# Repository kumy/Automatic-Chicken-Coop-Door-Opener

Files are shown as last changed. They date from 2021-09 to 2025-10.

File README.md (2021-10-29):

# Automatic Chicken Coop Door Opener

Here is my personal implementation of an Automatic Chicken Coop Door Opener. It has direct control button, a simple web interface with camera support and can be controlled via `MQTT` protocol. It is integrated in my home automation system.

This project requires materials:
- 3D printed parts
- An `Arduino` (duemilanove in my case, but any board should be okay)
- A `Raspberry` Pi (3 A+ in my case)
- `Raspberry Pi Camera` + `SV-6B` Infrared Ring (optional)
- A Stepper motor (project could be adapted to support DC motors)
- A Stepper driver (`DRV8825` in my case)
- A [Push Button Switch Box](https://www.aliexpress.com/item/4000121428780.html)
- A [box](https://www.aliexpress.com/item/33003227855.html) to protect electronics
- A `DS18b20` Temperature sensor
- Two [magnetic door sensor](https://www.amazon.fr/gp/product/B082PM18V6/) (I've choose mine brown)
- Some 4 wires cables, dupont cables and [Solder Seal Wire Connectors](https://www.aliexpress.com/item/1005002662810874.html)
- A [Waterproof Electrical Distribution Box](https://www.aliexpress.com/item/4001061820250.html)
- `5V` and `12V` [Industrial DIN Rail Switching Power Supply](https://www.aliexpress.com/item/4001289041252.html)
- 13cm diameter 8 steel rod
- Two `608` bearings
- Some washers and screws

# Raspberry Pi software installation

- First install your preferred Linux distribution (I've simply used Raspberry Pi
 OS).
- (optional) Install `motion`: `sudo apt install motion` (my config file in the `other` directory) and make it start at boot (edit `/etc/default/motion`)
- Install `redis server`: `sudo apt install redis-server` and enable start on boot `sudo systemctl enable redis-server`
- Clone this project GIT repository
- Install python required libraries: `sudo pip3 install -r requirements.txt`
- Install `gunicorn3` and `authbind`: `sudo apt install gunicorn3 authbind`
- Configure `authbind`: `sudo touch /etc/authbind/byport/80; sudo chmod 500 /etc/authbind/byport/80; sudo chown pi /etc/authbind/byport/80`
- Copy file `other/chicken-coop.service` to `/etc/systemd/system/chicken-coop.service`, then reload systemd (`sudo systemctl daemon-reload`) and enable the service `sudo systemctl enable chicken-coop.service`

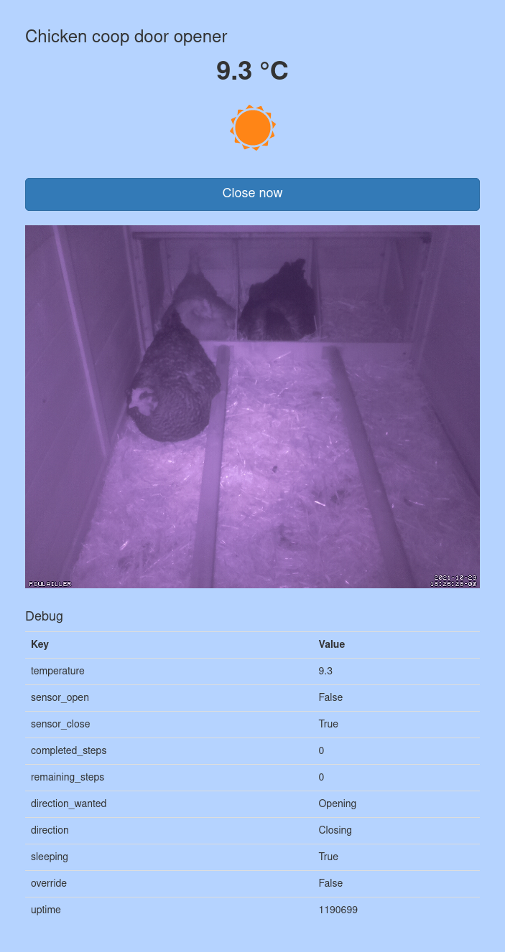
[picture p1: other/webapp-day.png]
WebAPP Day

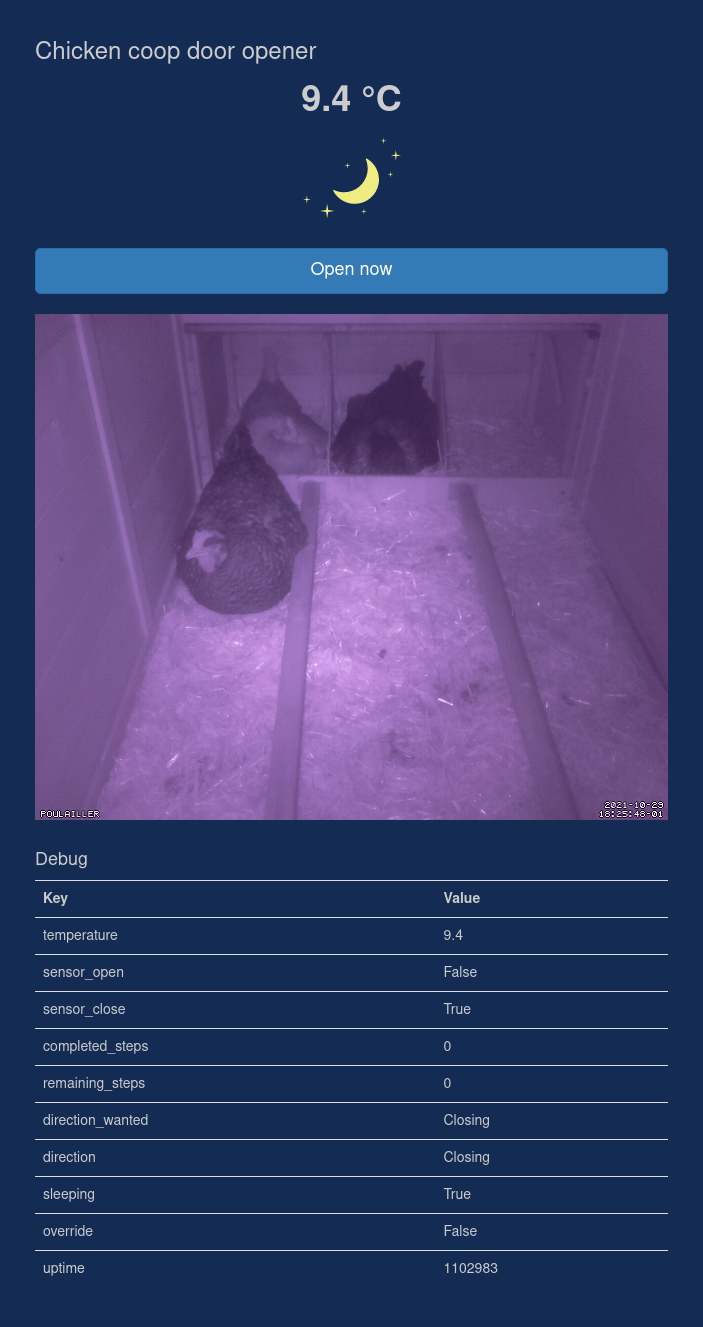
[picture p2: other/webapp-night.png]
WebAPP Day


# Electronic assembly

Please refer to the schema below to connect elements. Also **connect the Arduino to the Raspberry Pi via USB**, this is needed as they are communicating internally.

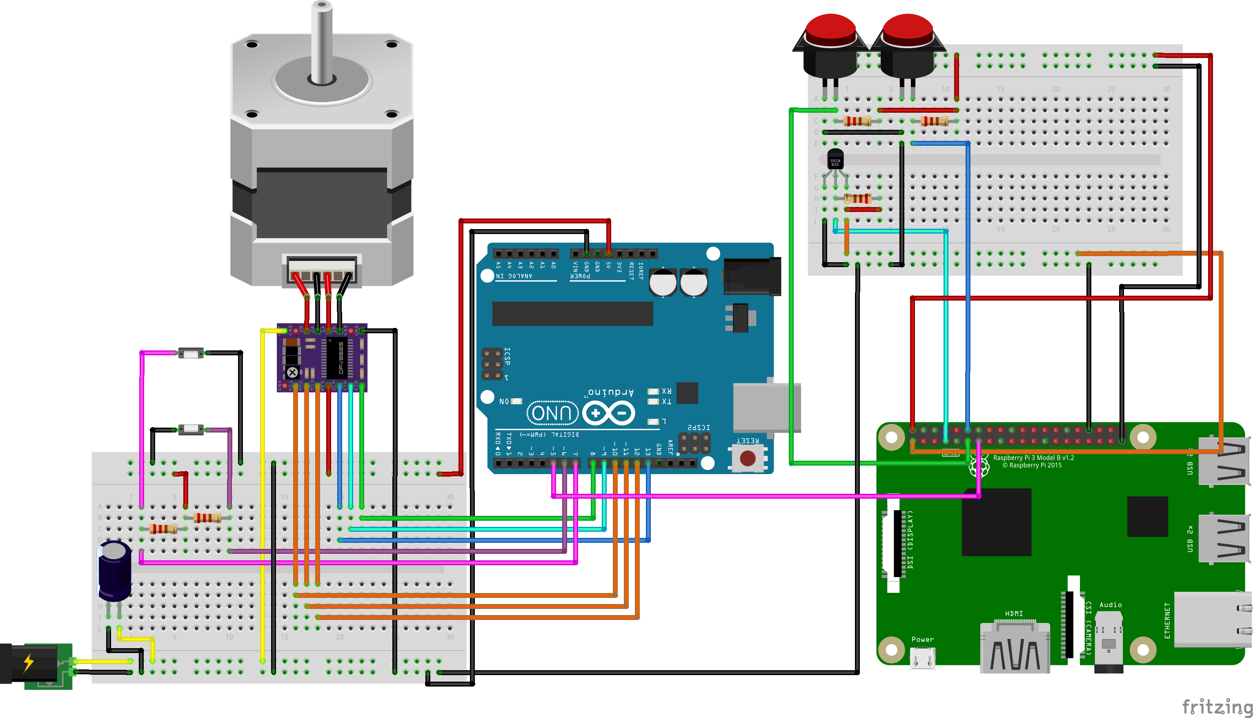
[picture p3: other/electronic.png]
Electronic assembly


## Arduino firmware upload

You'll find the arduino firmware in the `other/chicken_coop_arduino_v2` folder. You'll need to install libraries `ArduinoJson` and `StepperDriver`.

# Print 3D parts

Print files from folder `other/3D-parts`:
- `box.stl`
- `lead.stl`
- `drive-gear.stl`
- `stepper-gear.stl`
- `winder.stl`
- `IR-holder.stl`
- `IR-holder-base.stl`
- `case-without-clip.stl` (use some glue to paste it on `IR-holder.stl`)

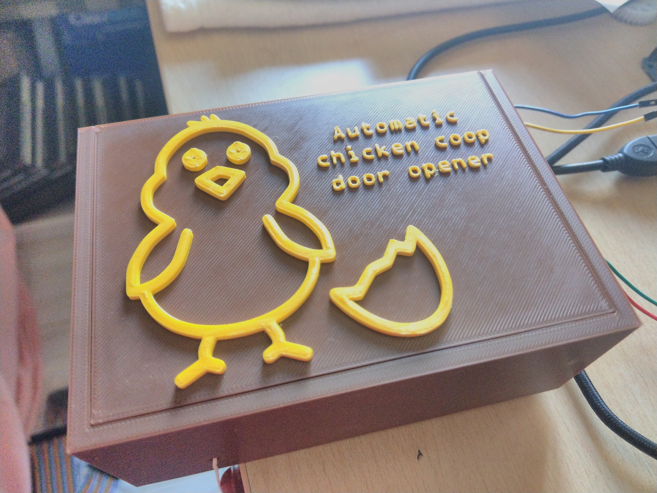
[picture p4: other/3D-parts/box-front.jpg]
Box front Front

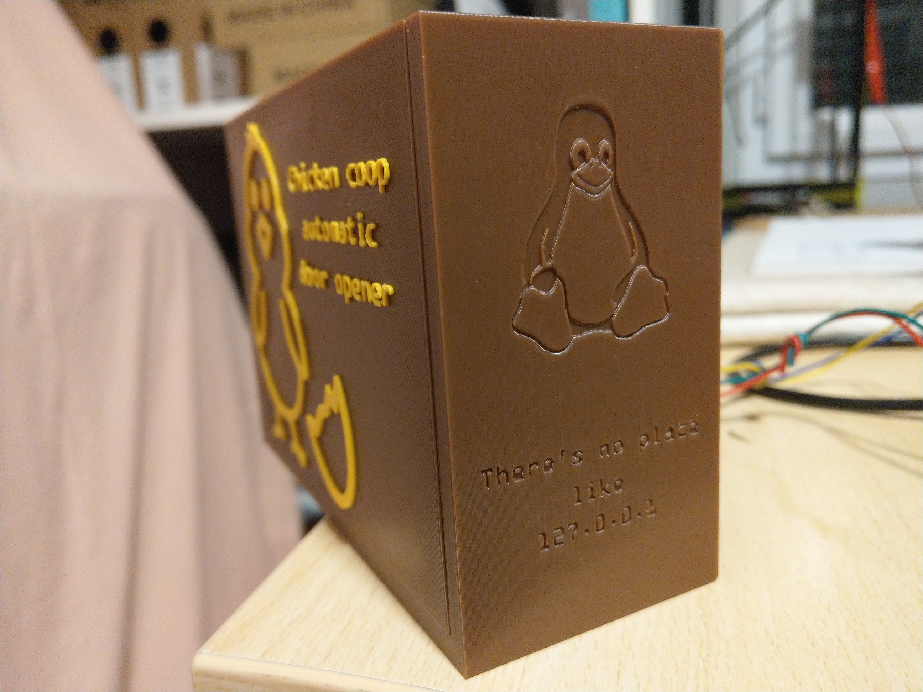
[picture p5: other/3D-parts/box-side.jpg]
Box side Side

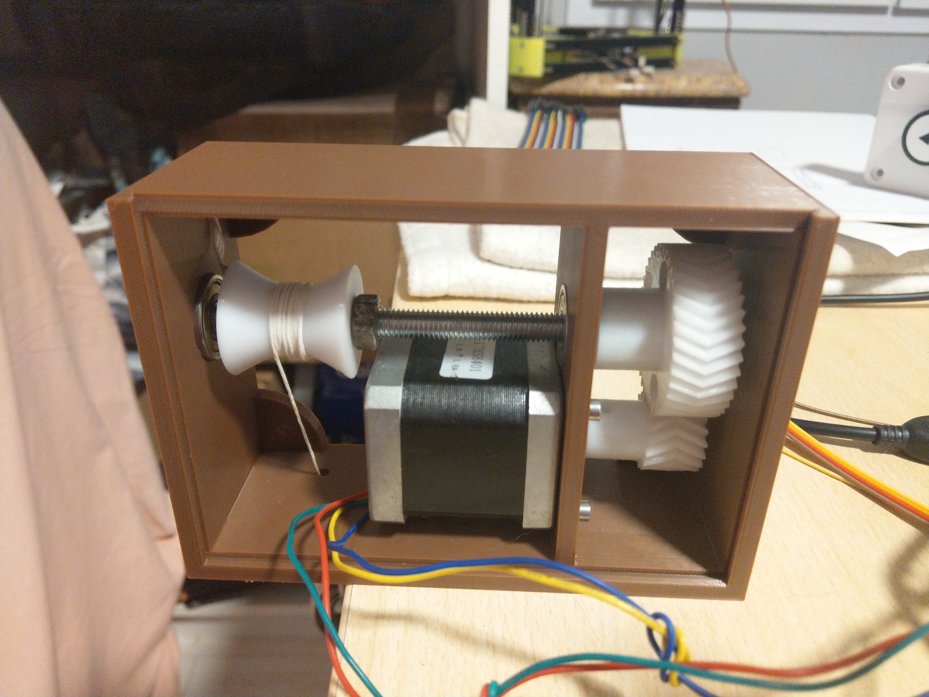
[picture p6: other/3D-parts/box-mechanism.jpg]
Box mechanism Mechanism


# Node-RED

I use [Node-RED](https://nodered.org/) to automate opening/closing the door according to the sun position.

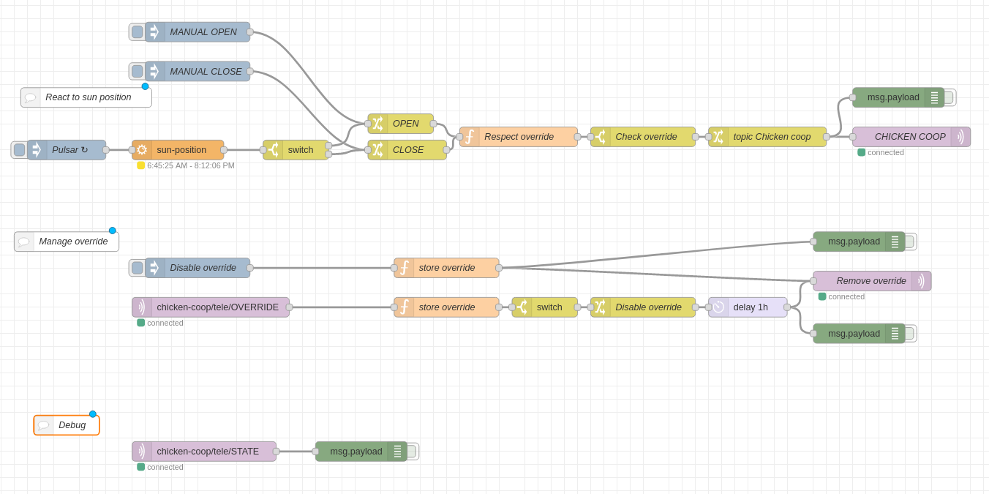
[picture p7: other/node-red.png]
Box front


```
[{"id":"c7d25223.e79a98","type":"tab","label":"Chicken coop","disabled":false,"info":""},{"id":"a1a07d72.5bd8","type":"inject","z":"c7d25223.e79a98","name":"MANUAL OPEN","props":[{"p":"payload"}],"repeat":"","crontab":"","once":false,"onceDelay":0.1,"topic":"","payload":"True","payloadType":"str","x":640,"y":100,"wires":[["fd09d4f.2c761a8","c0e33773.e7af7"]]},{"id":"5502c773.69c1b8","type":"inject","z":"c7d25223.e79a98","name":"MANUAL CLOSE","props":[{"p":"payload"}],"repeat":"","crontab":"","once":false,"onceDelay":0.1,"topic":"","payload":"True","payloadType":"str","x":640,"y":140,"wires":[["fd09d4f.2c761a8","2bb7edef.acf7e2"]]},{"id":"666bfd51.be461c","type":"change","z":"c7d25223.e79a98","name":"OPEN","rules":[{"t":"set","p":"payload","pt":"msg","to":"OPEN","tot":"str"}],"action":"","property":"","from":"","to":"","reg":false,"x":810,"y":280,"wires":[["63d5a226.1bf514"]]},{"id":"a247530a.950348","type":"change","z":"c7d25223.e79a98","name":"CLOSE","rules":[{"t":"set","p":"payload","pt":"msg","to":"CLOSE","tot":"str"}],"action":"","property":"","from":"","to":"","reg":false,"x":820,"y":340,"wires":[["63d5a226.1bf514"]]},{"id":"c711ead2.5034b8","type":"debug","z":"c7d25223.e79a98","name":"","active":false,"tosidebar":true,"console":false,"tostatus":false,"complete":"false","x":1510,"y":120,"wires":[]},{"id":"5edadbf0.16693c","type":"mqtt out","z":"c7d25223.e79a98","name":"CHICKEN COOP","topic":"chicken-coop/cmnd/ACTION","qos":"","retain":"","broker":"499038ea.d2406","x":1530,"y":260,"wires":[]},{"id":"6a6f2f23.bda448","type":"mqtt in","z":"c7d25223.e79a98","name":"","topic":"chicken-coop/tele/STATE","qos":"2","datatype":"auto","broker":"499038ea.d2406","x":430,"y":760,"wires":[["186cc186.50ee46"]]},{"id":"b574a3b.f240fe","type":"debug","z":"c7d25223.e79a98","name":"","active":false,"tosidebar":true,"console":false,"tostatus":false,"complete":"false","x":1010,"y":760,"wires":[]},{"id":"470b9cb6.7c8c3c","type":"sun-position","z":"c7d25223.e79a98","name":"","positionConfig":"9a8aa319.57d4a8","rules":[],"onlyOnChange":"true","topic":"","outputs":1,"start":"civilDawn","startType":"pdsTime","startOffset":"","startOffsetType":"none","startOffsetMultiplier":60000,"end":"civilDusk","endType":"pdsTime","endOffset":"-40","endOffsetType":"num","endOffsetMultiplier":"60000","x":390,"y":320,"wires":[["745ca347.8275c4","97193675.7260f8"]]},{"id":"4abdc73f.09fec8","type":"inject","z":"c7d25223.e79a98","name":"Pulsar","props":[{"p":"payload"},{"p":"topic","vt":"str"}],"repeat":"60","crontab":"","once":true,"onceDelay":0.1,"topic":"","payload":"","payloadType":"date","x":220,"y":320,"wires":[["470b9cb6.7c8c3c"]]},{"id":"97193675.7260f8","type":"switch","z":"c7d25223.e79a98","name":"sunInSky?","property":"payload.sunInSky","propertyType":"msg","rules":[{"t":"true"},{"t":"false"}],"checkall":"true","repair":false,"outputs":2,"x":630,"y":320,"wires":[["666bfd51.be461c"],["a247530a.950348"]]},{"id":"4dd9039d.c1e154","type":"mqtt in","z":"c7d25223.e79a98","name":"","topic":"chicken-coop/cmnd/OVERRIDE","qos":"2","datatype":"auto","broker":"499038ea.d2406","x":450,"y":600,"wires":[["5fbb85e.d93fe7c","35cb803c.ddd72"]]},{"id":"5fbb85e.d93fe7c","type":"function","z":"c7d25223.e79a98","name":"store override","func":"\n/* store state back into state machine */\nglobal.set('state.chicken-coop.override', msg.payload == \"True\");\n\nreturn msg;","outputs":1,"noerr":0,"initialize":"","finalize":"","x":760,"y":560,"wires":[["d9b4a67a.acd348"]]},{"id":"d9b4a67a.acd348","type":"switch","z":"c7d25223.e79a98","name":"IsOverride?","property":"payload","propertyType":"msg","rules":[{"t":"eq","v":"True","vt":"str"}],"checkall":"true","repair":false,"outputs":1,"x":930,"y":560,"wires":[["3ac436d.57ae84a"]]},{"id":"3ac436d.57ae84a","type":"change","z":"c7d25223.e79a98","name":"Disable override","rules":[{"t":"set","p":"payload","pt":"msg","to":"False","tot":"str"}],"action":"","property":"","from":"","to":"","reg":false,"x":1100,"y":560,"wires":[["5a4e03ee.41194c"]]},{"id":"104d8435.acb36c","type":"debug","z":"c7d25223.e79a98","name":"","active":false,"tosidebar":true,"console":false,"tostatus":false,"complete":"false","x":1510,"y":600,"wires":[]},{"id":"f03327b8.42df","type":"mqtt out","z":"c7d25223.e79a98","name":"","topic":"chicken-coop/cmnd/OVERRIDE","qos":"","retain":"","broker":"499038ea.d2406","x":1570,"y":500,"wires":[]},{"id":"546f0d20.38d7e4","type":"inject","z":"c7d25223.e79a98","name":"Disable override","props":[{"p":"payload"}],"repeat":"","crontab":"","once":false,"onceDelay":0.1,"topic":"","payload":"False","payloadType":"str","x":440,"y":480,"wires":[["f03327b8.42df"]]},{"id":"60c97cb0.cab624","type":"comment","z":"c7d25223.e79a98","name":"React to sun position","info":"","x":250,"y":240,"wires":[]},{"id":"58597c67.21380c","type":"comment","z":"c7d25223.e79a98","name":"Manage override","info":"","x":220,"y":460,"wires":[]},{"id":"14b453f.d74912c","type":"comment","z":"c7d25223.e79a98","name":"Debug","info":"","x":170,"y":1100,"wires":[]},{"id":"35cb803c.ddd72","type":"debug","z":"c7d25223.e79a98","name":"","active":false,"tosidebar":true,"console":false,"tostatus":false,"complete":"false","statusVal":"","statusType":"auto","x":750,"y":620,"wires":[]},{"id":"60601a56.7f041c","type":"debug","z":"c7d25223.e79a98","name":"","active":true,"tosidebar":true,"console":false,"tostatus":false,"complete":"false","statusVal":"","statusType":"auto","x":770,"y":1140,"wires":[]},{"id":"3c4749ab.162266","type":"inject","z":"c7d25223.e79a98","name":"Read override","props":[],"repeat":"","crontab":"","once":false,"onceDelay":0.1,"topic":"","x":390,"y":1140,"wires":[["37e30002.79cbb"]]},{"id":"37e30002.79cbb","type":"function","z":"c7d25223.e79a98","name":"isOverridden?","func":"\n/* store state back into state machine */\nmsg.payload = global.get('state.chicken-coop.override');\n\nreturn msg;","outputs":1,"noerr":0,"initialize":"","finalize":"","x":600,"y":1140,"wires":[["60601a56.7f041c"]]},{"id":"54d75f5.38342a","type":"inject","z":"c7d25223.e79a98","name":"Enable override","props":[{"p":"payload"}],"repeat":"","crontab":"","once":false,"onceDelay":0.1,"topic":"","payload":"True","payloadType":"str","x":440,"y":520,"wires":[["f03327b8.42df"]]},{"id":"5a4e03ee.41194c","type":"stoptimer","z":"c7d25223.e79a98","duration":"6","units":"Hour","payloadtype":"num","payloadval":"0","name":"","x":1290,"y":560,"wires":[["f03327b8.42df","104d8435.acb36c"],[]]},{"id":"a9ff0fb9.bc101","type":"inject","z":"c7d25223.e79a98","name":"Stop Timer","props":[{"p":"payload"}],"repeat":"","crontab":"","once":false,"onceDelay":0.1,"topic":"","payload":"STOP","payloadType":"str","x":1100,"y":660,"wires":[["5a4e03ee.41194c","be497be1.a9ea5"]]},{"id":"fd09d4f.2c761a8","type":"mqtt out","z":"c7d25223.e79a98","name":"","topic":"chicken-coop/cmnd/OVERRIDE","qos":"","retain":"","broker":"499038ea.d2406","x":1050,"y":40,"wires":[]},{"id":"32152b3.f4826d4","type":"debug","z":"c7d25223.e79a98","name":"","active":true,"tosidebar":true,"console":false,"tostatus":false,"complete":"false","statusVal":"","statusType":"auto","x":770,"y":1180,"wires":[]},{"id":"eeb76486.eddd1","type":"inject","z":"c7d25223.e79a98","name":"Read Position","props":[],"repeat":"","crontab":"","once":false,"onceDelay":0.1,"topic":"","x":390,"y":1180,"wires":[["c5474891.8ae5f8"]]},{"id":"c5474891.8ae5f8","type":"function","z":"c7d25223.e79a98","name":"isClosed?","func":"\n/* store state back into state machine */\nmsg.payload = global.get('state.chicken-coop.closed');\n\nreturn msg;","outputs":1,"noerr":0,"initialize":"","finalize":"","x":580,"y":1180,"wires":[["32152b3.f4826d4"]]},{"id":"186cc186.50ee46","type":"json","z":"c7d25223.e79a98","name":"","property":"payload","action":"","pretty":false,"x":630,"y":760,"wires":[["4e5b3f48.015bd"]]},{"id":"4e5b3f48.015bd","type":"function","z":"c7d25223.e79a98","name":"storePosition","func":"\n/* store state back into state machine */\nglobal.set('state.chicken-coop.closed', msg.payload.sensor_close == true);\n\nif (msg.payload.direction_wanted == 'Closing') {\n    global.set('state.chicken-coop.direction', 'CLOSE');\n} else {\n    global.set('state.chicken-coop.direction', 'OPEN');\n}\n\nreturn msg;","outputs":1,"noerr":0,"initialize":"","finalize":"","x":790,"y":760,"wires":[["b574a3b.f240fe","7bf97c0b.a1ba54"]]},{"id":"745ca347.8275c4","type":"debug","z":"c7d25223.e79a98","name":"","active":false,"tosidebar":true,"console":false,"tostatus":false,"complete":"false","statusVal":"","statusType":"auto","x":560,"y":380,"wires":[]},{"id":"be497be1.a9ea5","type":"change","z":"c7d25223.e79a98","name":"Disable override","rules":[{"t":"set","p":"payload","pt":"msg","to":"False","tot":"str"}],"action":"","property":"","from":"","to":"","reg":false,"x":1300,"y":660,"wires":[["104d8435.acb36c","f03327b8.42df"]]},{"id":"8fd65612.1fe63","type":"mqtt out","z":"c7d25223.e79a98","name":"","topic":"chicken-coop/tele/OVERRIDE","qos":"","retain":"","broker":"499038ea.d2406","x":1570,"y":940,"wires":[]},{"id":"cb084a44.8375f","type":"function","z":"c7d25223.e79a98","name":"readOverride","func":"\n/* store state back into state machine */\nmsg.payload = global.get('state.chicken-coop.override');\n\nreturn msg;","outputs":1,"noerr":0,"initialize":"","finalize":"","x":1310,"y":940,"wires":[["8fd65612.1fe63","5b164d4c.87ba54"]]},{"id":"34d8774f.bde0e","type":"inject","z":"c7d25223.e79a98","name":"Pulsar","props":[{"p":"payload"},{"p":"topic","vt":"str"}],"repeat":"300","crontab":"","once":true,"onceDelay":0.1,"topic":"","payload":"","payloadType":"date","x":220,"y":940,"wires":[["cb084a44.8375f"]]},{"id":"5b164d4c.87ba54","type":"debug","z":"c7d25223.e79a98","name":"","active":false,"tosidebar":true,"console":false,"tostatus":false,"complete":"false","statusVal":"","statusType":"auto","x":1520,"y":1000,"wires":[]},{"id":"7bf97c0b.a1ba54","type":"switch","z":"c7d25223.e79a98","name":"Is DirectionSameAsAuto?","property":"state.chicken-coop.direction","propertyType":"global","rules":[{"t":"eq","v":"state.chicken-coop.direction_auto","vt":"global"}],"checkall":"true","repair":false,"outputs":1,"x":1050,"y":820,"wires":[["be497be1.a9ea5"]]},{"id":"946ce4dc.017a88","type":"switch","z":"c7d25223.e79a98","name":"IsNotOverridden?","property":"state.chicken-coop.override","propertyType":"global","rules":[{"t":"false"}],"checkall":"true","repair":false,"outputs":1,"x":1230,"y":340,"wires":[["c711ead2.5034b8","5edadbf0.16693c"]]},{"id":"c0e33773.e7af7","type":"change","z":"c7d25223.e79a98","name":"OPEN","rules":[{"t":"set","p":"payload","pt":"msg","to":"OPEN","tot":"str"}],"action":"","property":"","from":"","to":"","reg":false,"x":970,"y":100,"wires":[["5edadbf0.16693c","c711ead2.5034b8"]]},{"id":"2bb7edef.acf7e2","type":"change","z":"c7d25223.e79a98","name":"CLOSE","rules":[{"t":"set","p":"payload","pt":"msg","to":"CLOSE","tot":"str"}],"action":"","property":"","from":"","to":"","reg":false,"x":980,"y":140,"wires":[["5edadbf0.16693c","c711ead2.5034b8"]]},{"id":"63d5a226.1bf514","type":"function","z":"c7d25223.e79a98","name":"storeDirectionAuto","func":"\n/* store state back into state machine */\nglobal.set('state.chicken-coop.direction_auto', msg.payload);\n\nreturn msg;","outputs":1,"noerr":0,"initialize":"","finalize":"","x":1010,"y":340,"wires":[["946ce4dc.017a88"]]},{"id":"68e3560f.696ce8","type":"debug","z":"c7d25223.e79a98","name":"","active":true,"tosidebar":true,"console":false,"tostatus":false,"complete":"false","statusVal":"","statusType":"auto","x":770,"y":1220,"wires":[]},{"id":"7b02d608.3a1578","type":"inject","z":"c7d25223.e79a98","name":"Read Direction Auto","props":[],"repeat":"","crontab":"","once":false,"onceDelay":0.1,"topic":"","x":410,"y":1220,"wires":[["1ab3a071.b7dd38"]]},{"id":"1ab3a071.b7dd38","type":"function","z":"c7d25223.e79a98","name":"direction_auto","func":"\n/* store state back into state machine */\nmsg.payload = global.get('state.chicken-coop.direction_auto');\n\nreturn msg;","outputs":1,"noerr":0,"initialize":"","finalize":"","x":600,"y":1220,"wires":[["68e3560f.696ce8"]]},{"id":"499038ea.d2406","type":"mqtt-broker","name":"MQTT - NAS","broker":"nas.house.kumy.net","port":"1883","clientid":"","usetls":false,"compatmode":false,"keepalive":"60","cleansession":true,"birthTopic":"","birthQos":"0","birthPayload":"","closeTopic":"","closeQos":"0","closePayload":"","willTopic":"","willQos":"0","willPayload":""},{"id":"9a8aa319.57d4a8","type":"position-config","name":"House","isValide":"true","longitude":"0","latitude":"0","angleType":"deg","timeZoneOffset":99,"timeZoneDST":0,"stateTimeFormat":"3","stateDateFormat":"12"}]
```

# License

This project is released under [GNU GPLv3](LICENSE) license.

# Credits

- The chicken egg is from [Icon Fonts](https://www.onlinewebfonts.com/icon/552882) and is licensed by CC BY 3.0
- The day night original svg is from [Free SVG](https://freesvg.org/day-and-night) and is licensed as Public Domain
- The electronic schematic image was generated using a self build [Fritzing](https://fritzing.org/) install.
- The Pi Camera mount with infrared ring is a derivative of [Thing ico
Simple PiCam Case/Mount](https://www.thingiverse.com/thing:2613031), [Infrared Ring Mount SV-6B](https://www.thingiverse.com/thing:643221) and [GoPro customizable mounts, and a library to expand](https://www.thingiverse.com/thing:62800)

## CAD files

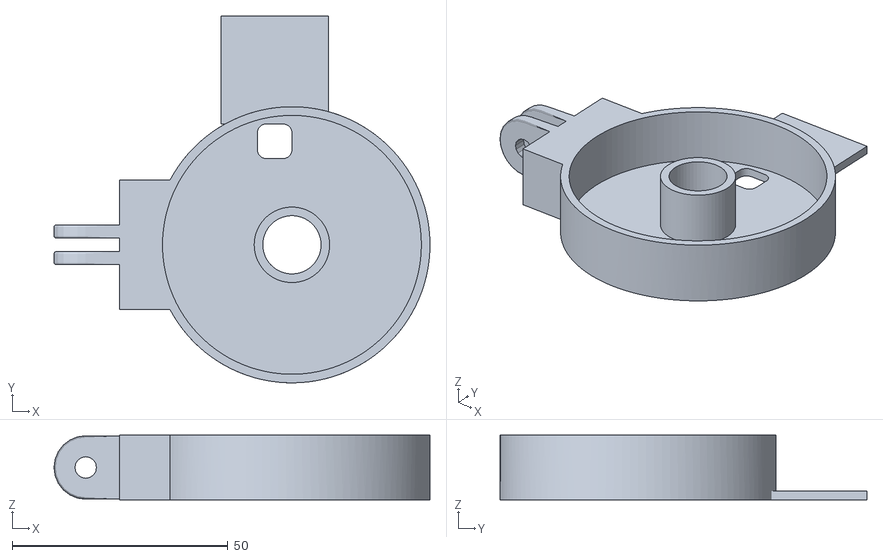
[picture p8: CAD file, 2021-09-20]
other/3D-parts/IR-holder.stl
87.2 x 85.0 x 15.0

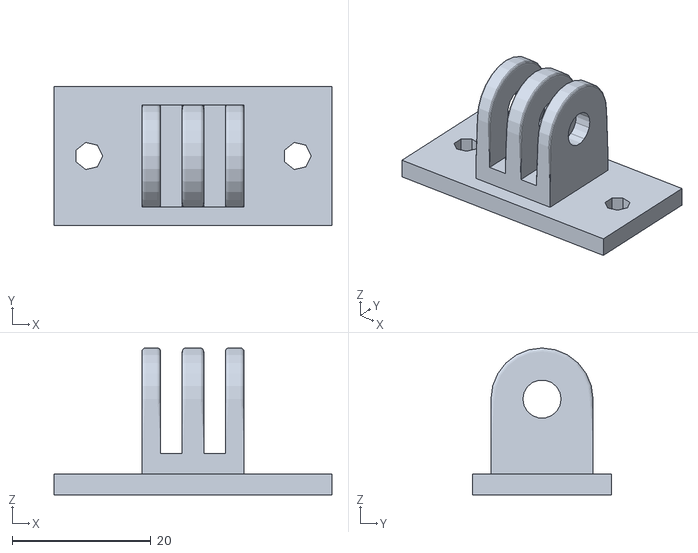
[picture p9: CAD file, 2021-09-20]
other/3D-parts/IR-holder-base.stl
40.0 x 20.0 x 21.1

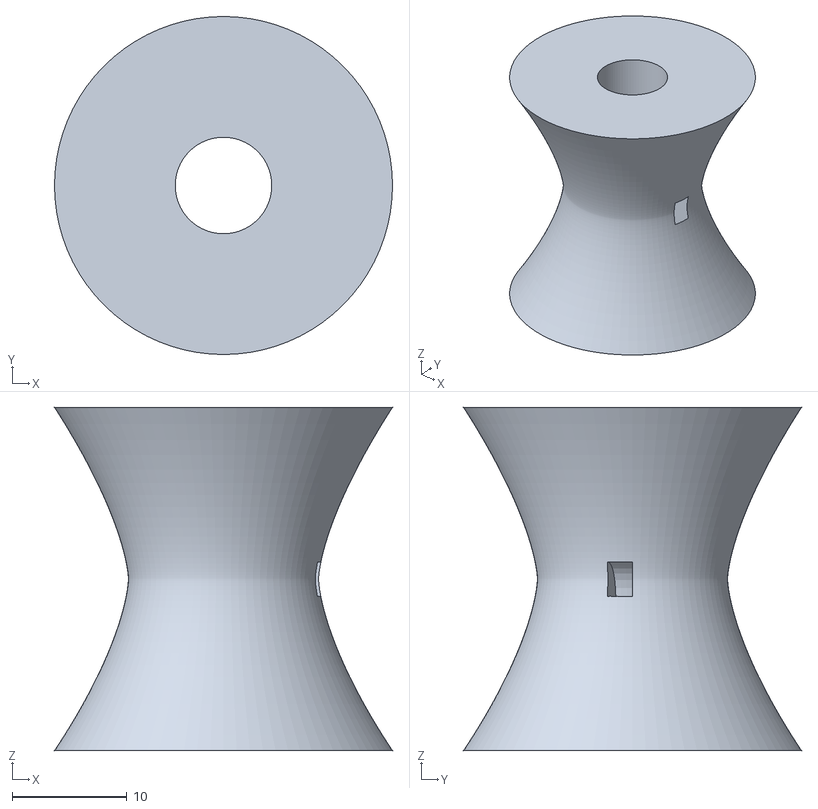
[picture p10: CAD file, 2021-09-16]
other/3D-parts/winder.stl
29.4 x 29.4 x 29.9

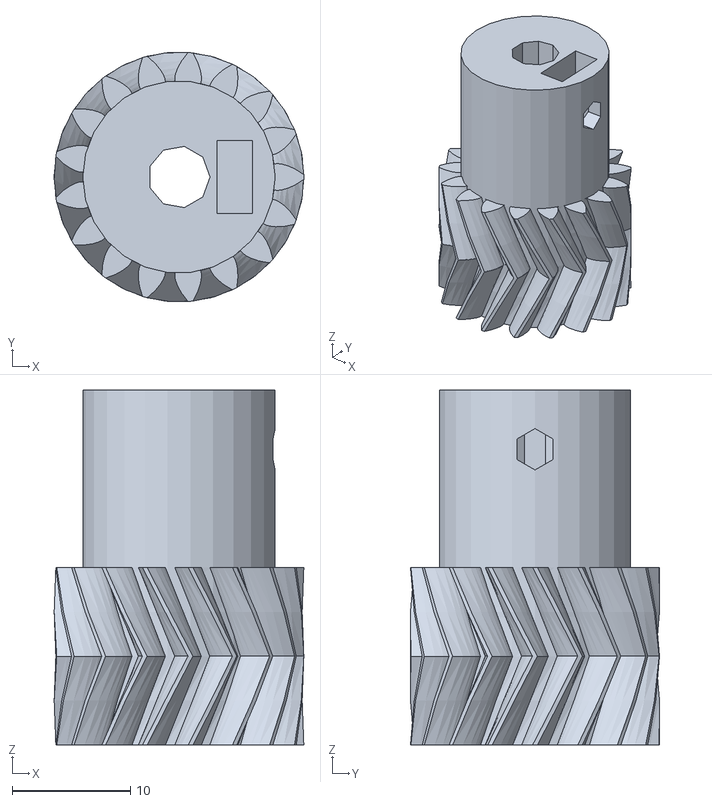
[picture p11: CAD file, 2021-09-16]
other/3D-parts/stepper-gear.stl
21.1 x 21.1 x 30.0

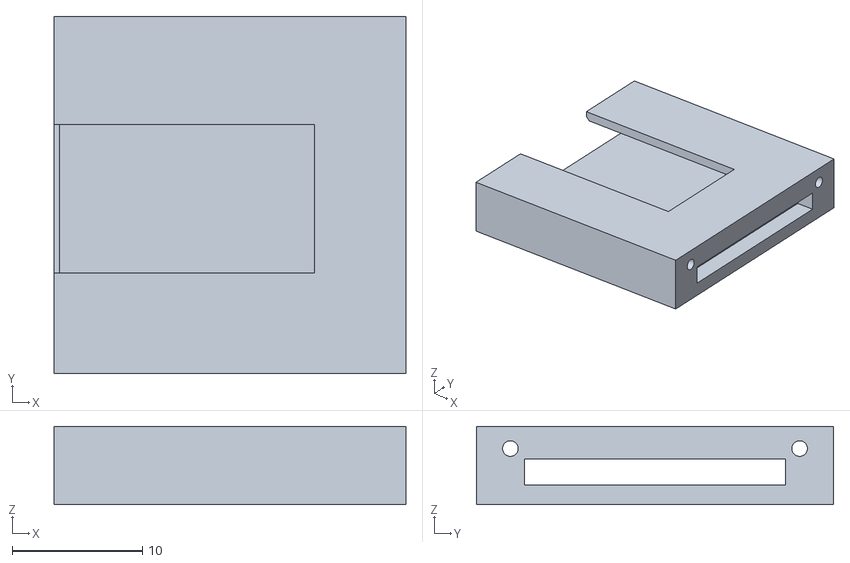
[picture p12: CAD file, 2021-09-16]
other/3D-parts/case-without-clip.stl
27.0 x 27.4 x 6.00

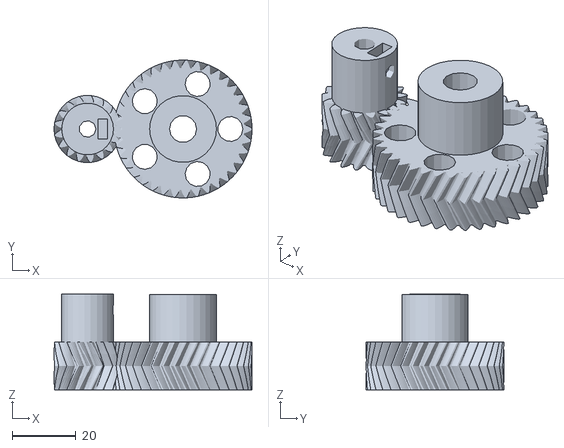
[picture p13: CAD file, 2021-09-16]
other/3D-parts/ParametricHerringboneGears.stl
62.2 x 43.3 x 30.0

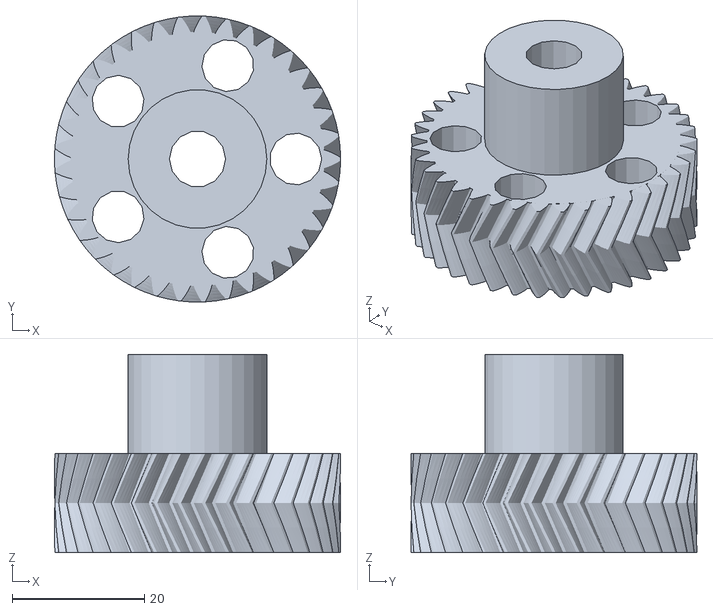
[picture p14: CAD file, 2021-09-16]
other/3D-parts/drive-gear.stl
43.3 x 43.3 x 30.0

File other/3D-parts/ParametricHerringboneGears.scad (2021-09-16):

// OpenSCAD Herringbone Wade's Gears Script
// (c) 2011, Christopher "ScribbleJ" Jansen
//
// Thanks to Greg Frost for his great "Involute Gears" script.
//
// Licensed under the BSD license.
include <MCAD/involute_gears.scad>


// WHAT TO GENERATE?
// generate = 0;    // GENERATE BOTH GEARS FOR VIEWING
// generate = 1;    // GENERATE STEPPER GEAR FOR PRINTING
generate = 2;    // GENERATE DRIVE GEAR FOR PRINTING

// OPTIONS COMMON TO BOTH GEARS:
distance_between_axels = 30;
gear_h = 15;
gear_shaft_h = 15;


// GEAR1 (SMALLER GEAR, STEPPER GEAR) OPTIONS:
// It's helpful to choose prime numbers for the gear teeth.
gear1_teeth = 17;
gear1_shaft_d = 5.25;  			// diameter of motor shaft
gear1_shaft_r  = gear1_shaft_d/2;
// gear1 shaft assumed to fill entire gear.
// gear1 attaches by means of a captive nut and bolt (or actual setscrew)
gear1_setscrew_offset = 5;			// Distance from motor on motor shaft.
gear1_setscrew_d         = 3.5;
gear1_setscrew_r          = gear1_setscrew_d/2;
gear1_captive_nut_d = 6.2;
gear1_captive_nut_r  = gear1_captive_nut_d/2;
gear1_captive_nut_h = 3;


// GEAR2 (LARGER GEAR, DRIVE SHAFT GEAR) OPTIONS:
gear2_teeth = 37;
gear2_shaft_d = 8.5;
gear2_shaft_r  = gear2_shaft_d/2;
// gear2 has settable outer shaft diameter.
gear2_shaft_outer_d = 21;
gear2_shaft_outer_r  = gear2_shaft_outer_d/2;

// gear2 has a hex bolt set in it, is either a hobbed bolt or has the nifty hobbed gear from MBI on it.
gear2_bolt_hex_d       = 15;
gear2_bolt_hex_r        = gear2_bolt_hex_d/2;
// gear2_bolt_sink: How far down the gear shaft the bolt head sits; measured as distance from drive end of gear.
gear2_bolt_sink          = 15;
// gear2's shaft is a bridge above the hex bolt shaft; this creates 1/3bridge_helper_h sized steps at top of shaft to help bridging.  (so bridge_helper_h/3 should be > layer height to have any effect)
bridge_helper_h=3;

gear2_rim_margin = 0;
gear2_cut_circles  = 5;

// gear2 setscrew option; not likely needed.
gear2_setscrew_offset = 0;
gear2_setscrew_d         = 0;
gear2_setscrew_r          = gear2_setscrew_d/2;
// captive nut for the setscrew
gear2_captive_nut_d = 0;
gear2_captive_nut_r  = gear2_captive_nut_d/2;
gear2_captive_nut_h = 0;


// Tolerances for geometry connections.
AT=0.02;
ST=AT*2;
TT=AT/2;


module bridge_helper()
{
	difference()
	{
		translate([0,0,-bridge_helper_h/2])
		cylinder(r=gear2_bolt_hex_r+TT, h=bridge_helper_h+TT,$fn=6,center=true);
		translate([0,0,-bridge_helper_h/2])
		cube([gear2_bolt_hex_d+ST, gear2_shaft_d, bridge_helper_h+AT], center=true);
	}
}



module gearsbyteethanddistance(t1=13,t2=51, d=60, teethtwist=1, which=1)
{
	cp = 360*d/(t1+t2);

	g1twist = 360 * teethtwist / t1;
	g2twist = 360 * teethtwist / t2;

	g1p_d  =  t1 * cp / 180;
	g2p_d  =  t2 * cp / 180;
	g1p_r   = g1p_d/2;
	g2p_r   = g2p_d/2;

	echo(str("Your small ", t1, "-toothed gear will be ", g1p_d, "mm across (plus 1 gear tooth size) (PR=", g1p_r,")"));
	echo(str("Your large ", t2, "-toothed gear will be ", g2p_d, "mm across (plus 1 gear tooth size) (PR=", g2p_r,")"));
	echo(str("Your minimum drive bolt length (to end of gear) is: ", gear2_bolt_sink+bridge_helper_h, "mm and your max is: ", gear_h+gear_shaft_h, "mm."));
	echo(str("Your gear mount axles should be ", d,"mm (", g1p_r+g2p_r,"mm calculated) from each other."));
	if(which == 1)
	{
		// GEAR 1
		difference()
		{
		union()
		{
			translate([0,0,(gear_h/2) - TT])
				gear(	twist = g1twist,
					number_of_teeth=t1,
					circular_pitch=cp,
					gear_thickness = gear_shaft_h + (gear_h/2)+AT,
					rim_thickness = (gear_h/2)+AT,
					rim_width = 0,
					hub_thickness = (gear_h/2)+AT,
					hub_width = 0,
					bore_diameter=0);

			translate([0,0,(gear_h/2) + AT])
			rotate([180,0,0])
				gear(	twist = -g1twist,
					number_of_teeth=t1,
					circular_pitch=cp,
					gear_thickness = (gear_h/2)+AT,
					rim_thickness = (gear_h/2)+AT,
					hub_thickness = (gear_h/2)+AT,
					bore_diameter=0);
		}
			//DIFFERENCE:
			//shafthole
			translate([0,0,-TT])
				cylinder(r=gear1_shaft_r, h=gear_h+gear_shaft_h+ST);

			//setscrew shaft
			translate([0,0,gear_h+gear_shaft_h-gear1_setscrew_offset])
				rotate([0,90,0])
				cylinder(r=gear1_setscrew_r, h=g1p_r);

			//setscrew captive nut
			translate([(g1p_r)/2, 0, gear_h+gear_shaft_h-gear1_captive_nut_r-gear1_setscrew_offset])
				translate([0,0,(gear1_captive_nut_r+gear1_setscrew_offset)/2])
					#cube([gear1_captive_nut_h, gear1_captive_nut_d, gear1_captive_nut_r+gear1_setscrew_offset+ST],center=true);


		}
	}
	else
	{
		// GEAR 2
		difference()
		{
		union()
		{
			translate([0,0,(gear_h/2) - TT])
				gear(	twist = -g2twist,
					number_of_teeth=t2,
					circular_pitch=cp,
					gear_thickness = gear_shaft_h + (gear_h/2)+AT,
					rim_thickness = (gear_h/2)+AT,
					rim_width = gear2_rim_margin,
					hub_diameter = gear2_shaft_outer_d,
					hub_thickness = (gear_h/2)+AT,
					bore_diameter=0,
					circles = gear2_cut_circles);

			translate([0,0,(gear_h/2) + AT])
			rotate([180,0,0])
				gear(	twist = g2twist,
					number_of_teeth=t2,
					circular_pitch=cp,
					gear_thickness = (gear_h/2)+AT,
					rim_thickness = (gear_h/2)+AT,
					rim_width = gear2_rim_margin,
					hub_diameter = gear2_shaft_outer_d,
					hub_thickness = (gear_h/2)+AT,
					bore_diameter=0,
					circles = gear2_cut_circles);
		}
			//DIFFERENCE:
			//shafthole
			translate([0,0,-TT])
				cylinder(r=gear2_shaft_r, h=gear_h+gear_shaft_h+ST);

			//setscrew shaft
			translate([0,0,gear_h+gear_shaft_h-gear2_setscrew_offset])
				rotate([0,90,0])
				cylinder(r=gear2_setscrew_r, h=gear2_shaft_outer_d);

			//setscrew captive nut
			translate([(gear2_shaft_outer_d)/2, 0, gear_h+gear_shaft_h-gear2_captive_nut_r-gear2_setscrew_offset])
				translate([0,0,(gear2_captive_nut_r+gear2_setscrew_offset)/2])
					#cube([gear2_captive_nut_h, gear2_captive_nut_d, gear2_captive_nut_r+gear2_setscrew_offset+ST],center=true);

			//trim shaft
			difference()
			{
				translate([0,0,gear_h+AT])	cylinder(h=gear_shaft_h+ST, r=g2p_r);
				translate([0,0,gear_h])	cylinder(h=gear_shaft_h, r=gear2_shaft_outer_r);
			}

			//hex bolt shaft
			translate([0,0,-TT]) cylinder(r=gear2_bolt_hex_r, h=gear_h+gear_shaft_h-gear2_bolt_sink+AT,$fn=6);

		}

		// hex bolt shaft bridge aid.
		translate([0,0,gear_h+gear_shaft_h-gear2_bolt_sink])
			bridge_helper();
		translate([0,0,gear_h+gear_shaft_h-gear2_bolt_sink+bridge_helper_h/3])
			rotate([0,0,60]) bridge_helper();
		translate([0,0,gear_h+gear_shaft_h-gear2_bolt_sink+((bridge_helper_h/3)*2)])
			rotate([0,0,-60]) bridge_helper();

	}

}


t1 = gear1_teeth;
t2 = gear2_teeth;
cp = 360*distance_between_axels/(t1+t2);
g1p_d  =  t1 * cp / 180;
g2p_d  =  t2 * cp / 180;
g1p_r   = g1p_d/2;
g2p_r   = g2p_d/2;

if(generate == 1)
{
	gearsbyteethanddistance(t1 = gear1_teeth, t2=gear2_teeth, d=distance_between_axels, which=1);
}
else if(generate == 2)
{
	gearsbyteethanddistance(t1 = gear1_teeth, t2=gear2_teeth, d=distance_between_axels, which=2);
}
else
{

	translate([-g1p_r,0,0]) rotate([0,0,($t*360/gear1_teeth)]) gearsbyteethanddistance(t1 = gear1_teeth, t2=gear2_teeth, d=distance_between_axels, which=1);
	translate([g2p_r,0,0])  rotate([0,0,($t*360/gear2_teeth)*-1]) gearsbyteethanddistance(t1 = gear1_teeth, t2=gear2_teeth, d=distance_between_axels, which=2);
}

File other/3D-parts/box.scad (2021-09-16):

/* use <MCAD/regular_shapes.scad> */

include <BOSL/nema_steppers.scad>
use <BOSL/nema_steppers.scad>

include <BOSL/constants.scad>
use <BOSL/metric_screws.scad>

include <ScrewsMetric/ScrewsMetric.scad>;
include <ScrewsMetric/Optional-Bearings.scad>;

box_lenght = 142;
box_width = 100;
box_height = 55;

box_border_width = 5;
box_pad_r = 20;
box_pad_h = 10;
box_pad_hole_r = 1.5;

box_gears_width = 30+5;

border_clearance = 5;
stepper_lenght = 48;
stepper_width = 42.3;
stepper_plinth = 2;

cover_height = 3;
cover_space_up = 2;

winder_lenght = 30;
winder_r = 15;
winder_clearance = 5;

bottom_relative = (-box_height + stepper_width)/2 + border_clearance;

/* box_cutter(); */
box();
/* lead(); */
elements();
/* tux(); */
/* text(); */

/* difference() {
  box();
  translate([box_lenght/2, -box_width/2, 0])
    cube([box_lenght+0.2, box_width+0.2, box_height+0.2], center=true);
} */

module box() {
  difference() {
    cube(size=[box_lenght, box_width, box_height], center=true);
    box_cutter();
    /* tux();
    text(); */
  }
}

module winder() { // -stepper_width +stepper_plinth - winder_lenght - winder_clearance -box_gears_width -2.5
  translate([-winder_lenght/2 +(box_lenght-box_border_width*2)/2 -box_gears_width-2.5-box_border_width - stepper_lenght -winder_clearance, -box_width/2+5 + box_border_width +stepper_width/2 +30 , bottom_relative])
    rotate([0,90,0])
      cylinder(r=winder_r, h=winder_lenght, center=true);
}

/* cable_hole(); */
cable_hole_r = 2;
module cable_hole() { // -stepper_width +stepper_plinth - winder_lenght - winder_clearance -box_gears_width -2.5
  color("green")
    translate([-winder_lenght/2 +(box_lenght-box_border_width*2)/2 -box_gears_width-2.5-box_border_width - stepper_lenght -winder_clearance,
          (-box_width+box_border_width)/2,
           bottom_relative-winder_r*3/4]) {
      rotate([0,90,90]) {
        cylinder(r=cable_hole_r, h=box_border_width+0.2, center=true);
      }
    }
}

module lead_slicing() {
    // lead slicing
    translate([0, box_border_width/4, box_height/2 + (-cover_space_up-cover_height/2)]) {
      difference() {
        color("green")
          cube(size=[box_lenght-box_border_width, box_width-box_border_width/2 +0.1, cover_height], center=true);

        color("blue")
          translate([0, -box_width/2-0.7, 0])
            rotate([-30,0,0])
              cube(size=[box_lenght, cover_height*2, cover_height*5], center=true);
        color("blue")
          translate([box_lenght/2-0.7, 0, 0])
            rotate([-30,0,90])
              cube(size=[box_lenght, cover_height*2, cover_height*5], center=true);
        color("blue")
          translate([-box_lenght/2+0.7, 0, 0])
            rotate([30,0,90])
              cube(size=[box_lenght, cover_height*2, cover_height*5], center=true);
      }

    }
}

module lead() {
  union() {
    translate([0, box_border_width/4, box_height/2 + (-cover_space_up-cover_height/2)]) {
      difference() {
        color("green")
          cube(size=[box_lenght-box_border_width-0.1, box_width-box_border_width/2, cover_height], center=true);

        color("blue")
          translate([0, -box_width/2-0.6, 0])
            rotate([-30,0,0])
              cube(size=[box_lenght, cover_height*2, cover_height*5], center=true);
        color("blue")
          translate([box_lenght/2-0.8, 0, 0])
            rotate([-30,0,90])
              cube(size=[box_lenght, cover_height*2, cover_height*5], center=true);
        color("blue")
          translate([-box_lenght/2+0.8, 0, 0])
            rotate([30,0,90])
              cube(size=[box_lenght, cover_height*2, cover_height*5], center=true);
      }

    }

    translate([0, box_border_width/2, box_height/2 + (-cover_space_up-cover_height)/2 +0.1]) {
      cube(size=[box_lenght-box_border_width*2-0.2, box_width-box_border_width, cover_space_up+cover_height], center=true);
    }

    text_chicken_coop();
    logo_chicken();
  }
}

module box_cutter() {
  color("red") {
    difference() {
      cube(size=[box_lenght-box_border_width*2, box_width-box_border_width*2, box_height+0.2], center=true);

      // Central separator
      translate([(box_lenght-box_border_width*2-box_border_width*2)/2-box_gears_width, 0, 0]) {
        difference() {
          cube(size=[box_border_width, box_width, box_height+0.3], center=true);
          // lead space
          translate([0, 0, box_height/2 + (-cover_space_up-cover_height)/2 +0.1]) {
            cube(size=[box_border_width+0.2, box_width+0.2, cover_space_up+cover_height+0.1], center=true);
          }
        }
      }

      // Pads
      translate([(box_lenght-box_border_width*2)/2, (box_width-box_border_width*2)/2, -box_height/2])
        cylinder(r=box_pad_r, h=box_pad_h, center=true);
      translate([(box_lenght-box_border_width*2)/2, -(box_width-box_border_width*2)/2, -box_height/2])
        cylinder(r=box_pad_r, h=box_pad_h, center=true);
      translate([-(box_lenght-box_border_width*2)/2, (box_width-box_border_width*2)/2, -box_height/2])
        cylinder(r=box_pad_r, h=box_pad_h, center=true);
      translate([-(box_lenght-box_border_width*2)/2, -(box_width-box_border_width*2)/2, -box_height/2])
        cylinder(r=box_pad_r, h=box_pad_h, center=true);
    }

    // lead space
    translate([0, box_width/2, box_height/2 + (-cover_space_up-cover_height)/2 +0.1]) {
      cube(size=[box_lenght-box_border_width*2, box_border_width*2+0.1, cover_space_up+cover_height+0.1], center=true);
    }

    // lead slicing
    lead_slicing();

    cable_hole();

    // Pads holes
    translate([(box_lenght-box_border_width*2)/2-box_pad_r/2.5, (box_width-box_border_width*2)/2-box_pad_r/2.5, -box_height/2])
      cylinder(r=box_pad_hole_r, h=box_pad_h+0.2, center=true);
    translate([(box_lenght-box_border_width*2)/2-box_pad_r/2.5, -(box_width-box_border_width*2)/2+box_pad_r/2.5, -box_height/2])
      cylinder(r=box_pad_hole_r, h=box_pad_h+0.2, center=true);
    translate([-(box_lenght-box_border_width*2)/2+box_pad_r/2.5, (box_width-box_border_width*2)/2-box_pad_r/2.5, -box_height/2])
      cylinder(r=box_pad_hole_r, h=box_pad_h+0.2, center=true);
    translate([-(box_lenght-box_border_width*2)/2+box_pad_r/2.5, -(box_width-box_border_width*2)/2+box_pad_r/2.5, -box_height/2])
      cylinder(r=box_pad_hole_r, h=box_pad_h+0.2, center=true);

    // motor mount
    translate([(box_lenght-box_border_width*2)/2-box_gears_width-box_border_width, -box_width/2 + box_border_width+5, bottom_relative])
      nema17_mount_holes(depth=5.2, l=0, orient=ORIENT_X, align=V_BACK);

    // bearings
    translate([(-box_lenght+box_border_width)/2, -box_width/2+5 + box_border_width +stepper_width/2 +30 , bottom_relative])
      rotate([0,90,0])
          cylinder(r=11, h=10, center=true);
    translate([(box_lenght-box_border_width*2)/2-box_gears_width-box_border_width, -box_width/2+5 + box_border_width +stepper_width/2 +30 , bottom_relative])
      rotate([0,90,0])
          cylinder(r=11, h=10, center=true);
  }
}


module elements() {
  // Gears
  color("cyan") {
  translate([(box_lenght-box_border_width*2)/2-box_gears_width+30, -box_width/2 + box_border_width+5 +30 +0.6, bottom_relative]) //-14.7
    rotate([90,180,-90])
      import("ParametricHerringboneGears.stl");
  }

  // stepper
  translate([(box_lenght-box_border_width*2)/2-box_gears_width-48+22-box_border_width, -box_width/2 + box_border_width+5, bottom_relative ])
      nema17_stepper(h=48, shaft_len=22, orient=ORIENT_X, align=V_BACK);

  // rod
  translate([-20, -box_width/2+5 + box_border_width +stepper_width/2 +30 , bottom_relative])
    rotate([0,90,0])
      cylinder(r=4, h=box_lenght-box_border_width, center=true);

  // nut
  rotate([0,0,0])
    translate([(box_lenght-box_border_width*2)/2-box_gears_width+30, -box_width/2+5 + box_border_width +stepper_width/2 +30 , bottom_relative -7.5])
      metric_nut(size=8, hole=true, pitch=1.5, details=true, orient=ORIENT_X);

  // bearings
  color("grey") {
    translate([(-box_lenght+box_border_width)/2-2.5, -box_width/2+5 + box_border_width +stepper_width/2 +30 , bottom_relative])
      rotate([0,90,0])
        BearingFromSize(M8);
    translate([(box_lenght-box_border_width*2)/2-box_gears_width-box_border_width-2.5, -box_width/2+5 + box_border_width +stepper_width/2 +30 , bottom_relative])
      rotate([0,90,0])
        BearingFromSize(M8);
  }
  winder();
}

module text() {
  _scale=1/3;
  color("purple")
  translate([box_lenght/2-box_border_width/8, -box_height/1.7, box_height/2 -5])
  scale([_scale, _scale, _scale])
  rotate([0, 90, 0])
  linear_extrude(height = 10, center = false, scale=1)
    import("thereisnoplacelike127.0.0.1.svg");
}

module text_chicken_coop() {
  _scale=3/4;
  color("purple")
  translate([29,20,  box_height/2-1])
  scale([_scale, _scale, 1])
  /* rotate([0, 90, 0]) */
  linear_extrude(height = 2, center = false, scale=1)
    import("chicken-text.svg", center=true);
}
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

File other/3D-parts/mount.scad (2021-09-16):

import("InfraredRingHolder-NoSupport.stl");

  translate([-25/2, 28, 0])
    cube([25,25,2], center=false);

/* difference() {
  rotate([0, -90, 0])
    import("case.stl");

  translate([0, 0, -11.001])
    cube([60,40,10], center=true);
} */

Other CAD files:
other/3D-parts/winder.scad

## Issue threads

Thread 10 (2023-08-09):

Parts question

KidA001, 2023-08-09:
Thank you for this writeup, this is great and exactly what I was looking for. Helping a friend automate the door on his coop.

I have a question on some of the parts you used. You didn't list the stepper motor you used but I could see `17HS8401` written on it so I'm assuming it's a Nema17  17HS8401? Do you have the exact one you used? I'd love to make sure the mounting points match up.

Also I'm unclear on the rod you mention, you said `13cm diameter 8 steel rod` in the readme, but I see a threaded rod in there. Do you have any more info on what you used?

Much appreciated!

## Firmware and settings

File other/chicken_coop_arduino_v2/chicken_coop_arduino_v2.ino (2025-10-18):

#include <Arduino.h>
#include <ArduinoJson.h>

StaticJsonDocument<200> stats;
unsigned long status_throttle = millis();
#define STATUS_THROTTLE 1000

#define MOTOR_STEPS 200
#define MICROSTEP 16  // Changed from 32 to reduce high-frequency noise (1/16 is quieter than 1/32)
#define RPM 30
#define MAX_ROTATE_DEGREES 360 * 13

#define DIR 8
#define STEP 9
#define SLEEP 13

#define READ_DIRECTION_PIN 5
#define SENSOR_CLOSED_PIN 6
#define SENSOR_OPEN_PIN 7

#include "DRV8825.h"
#define MODE0 10
#define MODE1 11
#define MODE2 12
DRV8825 stepper(MOTOR_STEPS, DIR, STEP, SLEEP, MODE0, MODE1, MODE2);

#define OPEN HIGH
#define CLOSE LOW

#define OPENING 1
#define CLOSING -1

// Debounce configuration
#define DEBOUNCE_DELAY 20  // 20ms debounce time

// Debounce state tracking
unsigned long lastSensorOpenDebounce = 0;
unsigned long lastSensorCloseDebounce = 0;
unsigned long lastDirectionDebounce = 0;
bool lastSensorOpenState = 1;
bool lastSensorCloseState = 1;
bool lastDirectionState = 1;

// Debounce function for noise-resistant sensor reading
bool debouncedRead(int pin, bool &lastState, unsigned long &lastDebounce) {
  bool reading = digitalRead(pin);

  // If the reading has changed, reset the debounce timer
  if (reading != lastState) {
    lastDebounce = millis();
    lastState = reading;
  }

  // Only accept the new reading if it has been stable for DEBOUNCE_DELAY
  if ((millis() - lastDebounce) > DEBOUNCE_DELAY) {
    return reading;
  }

  // Return the last stable state if not enough time has passed
  return lastState;
}

void setup() {
    Serial.begin(115200);
    stepper.begin(RPM);
    stepper.setMicrostep(MICROSTEP);

    // Configure sensor pins with pull-up resistors to prevent floating inputs
    pinMode(SENSOR_OPEN_PIN, INPUT_PULLUP);
    pinMode(SENSOR_CLOSED_PIN, INPUT_PULLUP);
    pinMode(READ_DIRECTION_PIN, INPUT_PULLUP);
}

bool read_sensor_open() {
  return !debouncedRead(SENSOR_OPEN_PIN, lastSensorOpenState, lastSensorOpenDebounce);
}
bool read_sensor_close() {
  return !debouncedRead(SENSOR_CLOSED_PIN, lastSensorCloseState, lastSensorCloseDebounce);
}
bool is_sleeping() {
  return !digitalRead(SLEEP);
}

void send_status() {
  if (millis() - status_throttle >= STATUS_THROTTLE) {
    stats["sensor_open"] = read_sensor_open();
    stats["sensor_close"] = read_sensor_close();
    stats["completed_steps"] = stepper.getStepsCompleted();
    stats["remaining_steps"] = stepper.getStepsRemaining();
    stats["direction_wanted"] = (debouncedRead(READ_DIRECTION_PIN, lastDirectionState, lastDirectionDebounce) == OPENING ? "Opening" : "Closing");
    stats["direction"] = (stepper.getDirection() == 1 ? "Opening" : "Closing");
    stats["sleeping"] = is_sleeping();
    stats["uptime"] = millis();
    serializeJson(stats, Serial);
    Serial.println();  // Add newline for Python parser
    status_throttle = millis();
  }
}

void read_direction() {
  bool direction = debouncedRead(READ_DIRECTION_PIN, lastDirectionState, lastDirectionDebounce);

  if (direction == OPEN && !read_sensor_open()) {
    if (stepper.getDirection() == CLOSING || read_sensor_close() && is_sleeping()) {
      stepper.startRotate(OPENING * MAX_ROTATE_DEGREES);
      stepper.enable();
    }
  }
  if (direction == CLOSE && !read_sensor_close()) {
    if (stepper.getDirection() == OPENING || read_sensor_open() && is_sleeping()) {
      stepper.startRotate(CLOSING * MAX_ROTATE_DEGREES);
      stepper.enable();
    }
  }
}

void check_endstop() {
  if (stepper.getDirection() == OPENING && read_sensor_open()) {
    stepper.stop();
  }
  if (stepper.getDirection() == CLOSING && read_sensor_close()) {
    stepper.stop();
  }
}

void loop() {
    check_endstop();
    read_direction();

    // motor control loop - send pulse and return how long to wait until next pulse
    unsigned wait_time_micros = stepper.nextAction();

    // 0 wait time indicates the motor has stopped
    if (wait_time_micros <= 0) {
        // Keep motor powered when door is open (holds position against gravity)
        // Disable motor when closed
        if (read_sensor_close()) {
            stepper.disable();
        }
        // If door is open: motor stays enabled to hold position
        send_status();
    }

    // (optional) execute other code if we have enough time
    if (wait_time_micros > 10){
        send_status();
    }
}

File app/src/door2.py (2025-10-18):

import argparse
import glob
import logging
import os
import sys

import asyncio
import json
import socket
import time
import uuid

import serial_asyncio
from aioesphomeapi.api_pb2 import SwitchStateResponse, \
    STATE_CLASS_MEASUREMENT, STATE_CLASS_TOTAL_INCREASING
from aioesphomeserver import (
    Device,
    SwitchEntity, SensorEntity, EntityListener, BinarySensorEntity,
)
import apigpio
from statistics import mean

from aioesphomeapi.model import SensorStateClass

APIGPIO_HOST = "192.168.130.196"
DEVICE_PORT = "/dev/ttyUSB0"

ENTITY_PREFIX = "Chicken Coop"
ENTITY_SLUG_PREFIX = "chicken_coop"

BUTTON_OPEN_GPIO = 17
BUTTON_CLOSE_GPIO = 18
DIRECTION_GPIO = 27  # way pin ON==open

# b = type('', (), {})()
# b.this_works = {}

logger = logging.getLogger(__name__)

# Double-press safety feature: buttons must be pressed twice within time window
DOUBLE_PRESS_MIN_DELAY = 0.5  # seconds - minimum time between presses (prevents bounce)
DOUBLE_PRESS_MAX_DELAY = 3.0  # seconds - maximum time between presses (timeout)
button_press_state = {
    'open': {'count': 0, 'timestamp': 0},
    'close': {'count': 0, 'timestamp': 0}
}


def setup_logging(log_level: str = "DEBUG") -> None:
    """Configure logging with the specified level.

    Args:
        log_level: Logging level (DEBUG, INFO, WARNING, ERROR, CRITICAL)
    """
    numeric_level = getattr(logging, log_level.upper(), logging.DEBUG)
    logging.basicConfig(
        level=numeric_level,
        format='%(asctime)s - %(name)s - %(levelname)s - %(message)s',
        datefmt='%Y-%m-%d %H:%M:%S'
    )
    logger.setLevel(numeric_level)


# Serial receive status as json 115200
# {
#     "sensor_open": true/false,
#     "sensor_close": true/false,
#     "completed_steps": 0,
#     "remaining_steps": 0,
#     "direction_wanted": "Opening/Closing",
#     "direction": "Opening/Closing",
#     "sleeping": true/false,
#     "uptime": 0
# }

class TemperatureSensorListener(EntityListener):
    _previous = None

    async def can_handle(self, key, message):
        return False

    async def run(self):
        def read():
            devices = glob.glob("/sys/bus/w1/devices/28*/temperature")
            temperatures = []
            for device in devices:
                with open(device) as f:
                    t = f.read()
                    if t != '':
                        temperatures.append(int(t) / 1000.0)
            try:
                avg = round(mean(temperatures), 1)
            except (ValueError, ZeroDivisionError, Exception) as e:
                logger.warning(f"Temperature calculation failed: {e}")
                avg = None
            return avg

        sensor = self.device.get_entity(f"{ENTITY_SLUG_PREFIX}_temperature_sensor")
        while True:
            temperature = read()
            if temperature is not None and self._previous != temperature:
                self._previous = temperature
                await sensor.set_state(temperature)
            await asyncio.sleep(60)


class UptimeListener(EntityListener):
    async def can_handle(self, key, message):
        return False

    async def run(self):
        sensor = self.device.get_entity(f"{ENTITY_SLUG_PREFIX}_uptime")
        while True:
            uptime = int(time.clock_gettime(time.CLOCK_BOOTTIME))
            logger.debug(f'reading uptime: {uptime}')
            await sensor.set_state(uptime)
            await asyncio.sleep(60)


class DoorSwitchListener(EntityListener):
    _porte_ouverte = None
    _previous = None

    def __init__(self, *args, **kwargs):
        super().__init__(*args, **kwargs)

    async def can_handle(self, key, message):
        if not isinstance(message, SwitchStateResponse):
            return False
        return await super().can_handle(key, message)

    async def handle(self, key, message):
        sensor = self.device.get_entity(f"{ENTITY_SLUG_PREFIX}_ouverture_porte")
        if sensor is not None:
            self._porte_ouverte = message.state

    async def run(self):
        while True:
            if self._previous != self._porte_ouverte:
                self._previous = self._porte_ouverte
                if self._porte_ouverte:
                    logger.info('ouverture')
                    await gate.open()
                else:
                    logger.info('fermeture')
                    await gate.close()
            await asyncio.sleep(0.1)


class EntityListenerFromSerial(EntityListener):
    # previous_ = None

    async def can_handle(self, key, message):
        return False

    # def set_state(self, sensor, key, interval=1):
    #     try:
    #         sensor_ = self.device.get_entity(f"{ENTITY_SLUG_PREFIX}_{sensor}")
    #         if sensor_ is not None and key in b.this_works:
    #             val = b.this_works[key]
    #             if val != self.previous_:
    #                 self.previous_ = val
    #                 print(f'reading {key}: {val}')
    #                 if val == "Opening":
    #                     val = True
    #                 elif val == "Closing":
    #                     val = False
    #                 elif key == 'uptime':
    #                     val = int(val/1000)
    #                 # await sensor_.set_state(val)
    #                 sensor_.set_state(val)
    #                 print("DEBUG 1.0")
    #             # else:
    #             #     print("DEBUG 1.1")
    #         else:
    #             print(f"DEBUG 1.2 {key}")
    #             if sensor_ is None:
    #                 print("sensor_ is None")
    #             print(b.this_works)
    #         # await asyncio.sleep(interval)
    #     except Exception as e:
    #         print(e)
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

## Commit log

2021-09-16 Initial release
    [IR-holder.stl, ParametricHerringboneGears.scad, ParametricHerringboneGears.stl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]
2021-09-20 Add IR holder mount
    [IR-holder-base.stl, IR-holder.stl]
2021-10-19 Add button debouncing
2021-10-24 Rework override
    Add transmit info back to main board
2025-10-18 feat(coop): add sensor debouncing for noise reduction
    [chicken_coop_arduino_v2.ino]
2025-10-18 fix(motor): reduce microstep from 32 to 16 for noise reduction
    [chicken_coop_arduino_v2.ino]
2025-10-18 feat: migrate Flask web UI to async ESPHome device
